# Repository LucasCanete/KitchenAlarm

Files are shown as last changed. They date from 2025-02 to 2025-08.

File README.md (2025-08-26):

# KitchenAlarm
A small Atmega168 based Kitchentimer to measure cooking time for your meals. Forget about downloading another app or using your phone. Do it the old fashioned way, like  it's the 90's. Put the pizza in the oven, configure your Kitchenalarm and let it beep like a fire alarm on steroids when your pizza is ready.

## Table of Contents
1. [About the Project](#about-the-project)
2. [Features](#features)
3. [Components](#components)
4. [Getting Started](#getting-started)
5. [Project Status](#project-status)

## About the project
This one was one of my first projects writing bare metal C. What i wanted to do is develop the simplest device possible, write the software, make a pcb and print a 3D case for it. A Timer is a device everyone is familiar with, so i decided to go for that. I took an atmega168, programmed it using avrdude and made a simple pcb for the circuitry using KiCad. Using the OnShape software i designed a case for the pcb and this was the end result.

## Features
- Rotary Encoder for configuring minutes and seconds
- 4 Digit 7 Segment Display for displaying the time
- Buzzer Alarm for beeping when time has runned up
- Deep sleep Mode after 1 Minute of not receiving instructions
- USB-C charger port with leds for indicating charging status

## Components
| Component | Model  | Manufacturer  |
|:---|:---:|---:|
| Microcontroller  | atmega168 | Microchip |
| 7 Seg. Display  | Generic | - |
| Rotary Encoder Module  | KY-040 | - |
| Battery Charger  | BQ24090 | Texas Instruments |

## Getting Started
### Install AVRDUDE
```
sudo apt install avrdude
```
### Download this repo
```
git clone https://github.com/LucasCanete/KitchenAlarm.git
```
### Build and upload 
Connect the KitchenAlarm to the PC using usbasp and upload the code:
```
cd KitchenAlarm/Software
$KitchenAlarm/Software make
$KitchenAlarm/Software make flash
```
### Use
The Kitchenalarm has a **Rotary Encoder** that lets you configure the Minutes and Seconds through the encoder's rotation.
1. Press the Rotary Encoder on the board to configure the Minutes and adjust it rotating the encoder 
2. Press it once again to configure the Seconds and rotate it to adjust 
3. Press the encoder one last time to activate the Timer with the Minutes and Seconds you configured in step 1 and step 2. The Timer will start counting down on the 7-Segment Display (To reset the countdown press the Encoder)
4. When the Timer reaches 00:00 (on the Display) the buzzer on the Board will start beeping. Your pizza is ready. Press the Encoder once to stop the beeping
5. The Kitchenalarm goes automatically to deep sleep if it is not given instructions. To wake it up just press the Encoder

<p align="center">
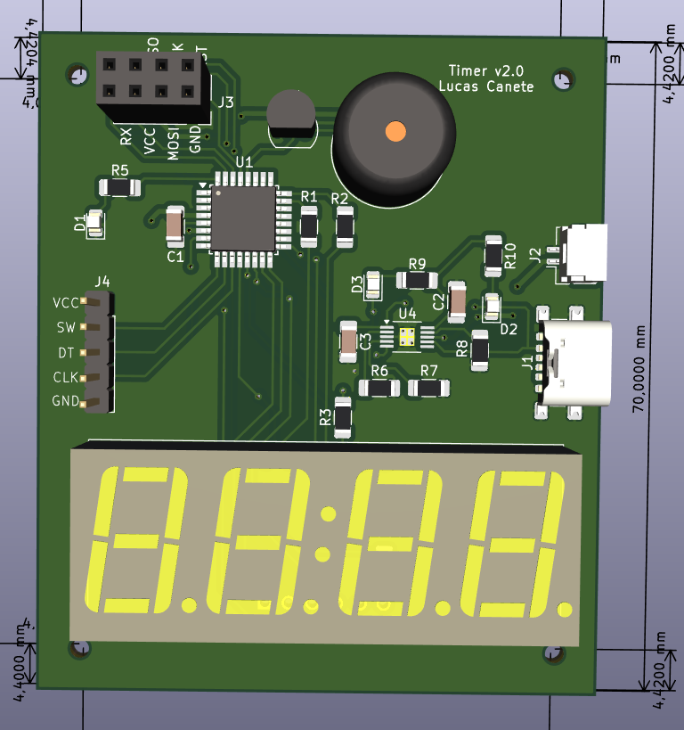
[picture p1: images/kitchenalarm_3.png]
Design
    
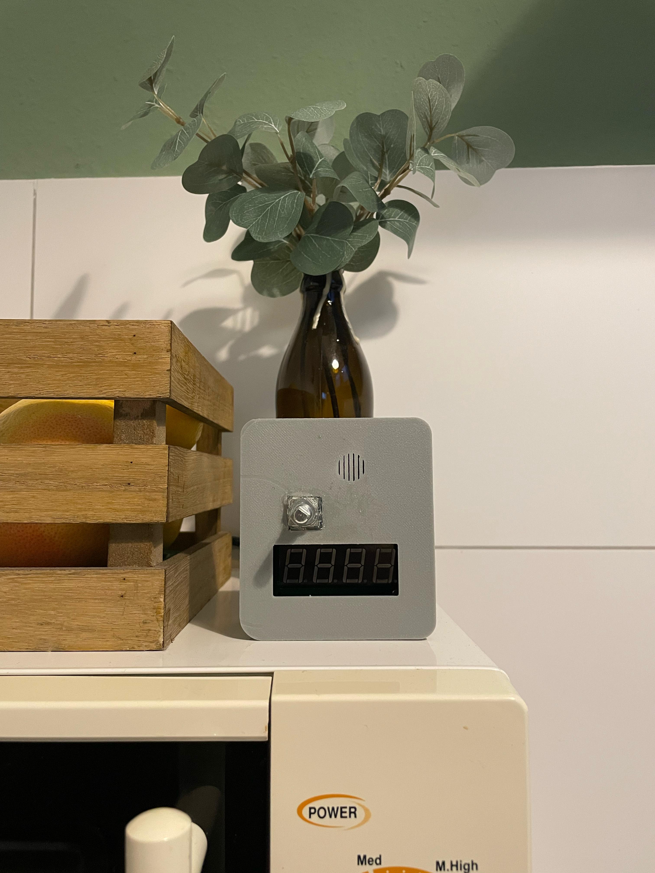
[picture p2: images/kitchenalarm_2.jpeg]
kitchenalarm
   
</p>

## Project Corretions
The project is still under development. Here are some improvement points for the next version. Crossed points havve alredy been implemented in the kicad design.
- [x] Add Rd resistors to USB-C for it to be detected as a passive device
- [x] Add resistor to buzzer transistor
- [ ] Use driver for efficient control of 7 segment display (MAX7219 or TM1637)

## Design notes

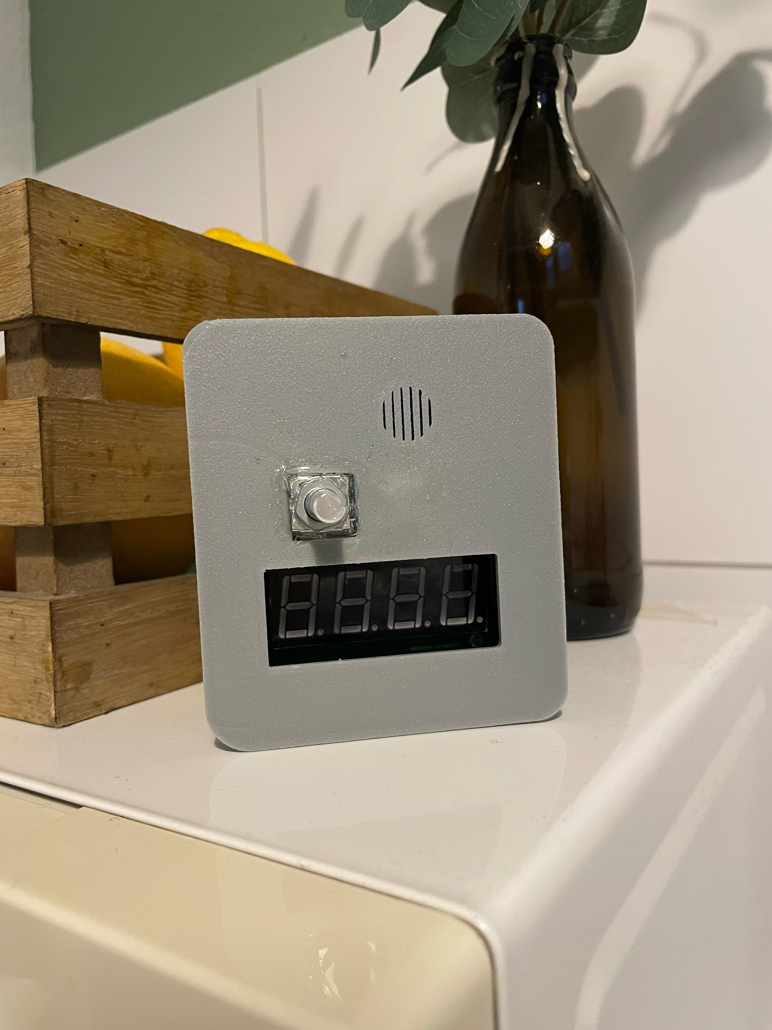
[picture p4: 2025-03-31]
images/kitchenalarm_1.jpeg

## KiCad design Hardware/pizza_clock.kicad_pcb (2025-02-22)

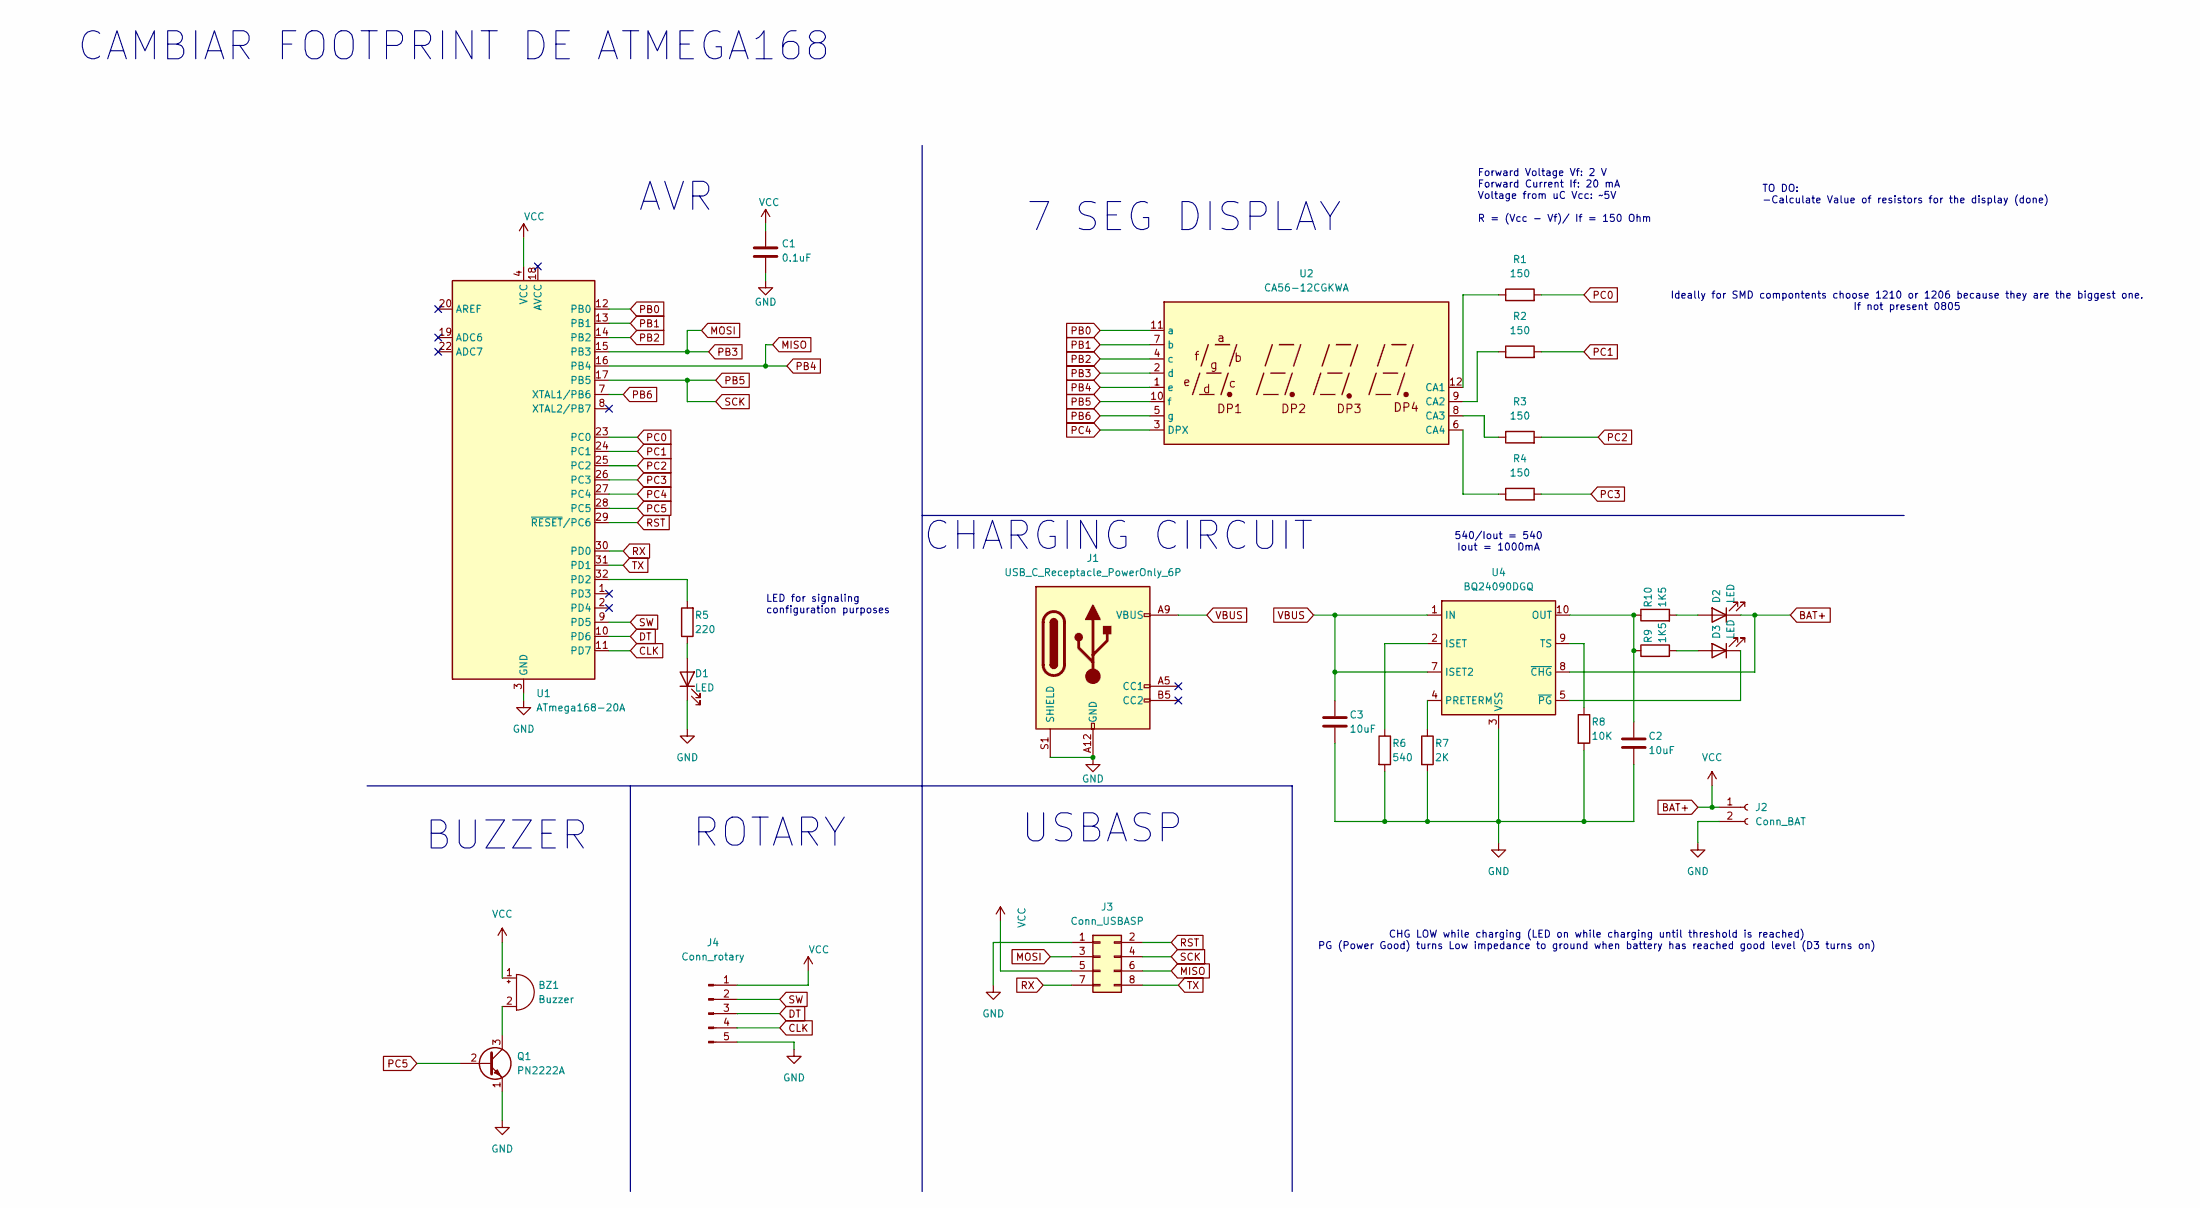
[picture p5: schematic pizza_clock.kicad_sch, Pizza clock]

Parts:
BZ1: Buzzer; Buzzer_12x9.5RM7.6
C1: 0.1uF; C_1206_3216Metric_Pad1.33x1.80mm_HandSolder
C2, C3: 10uF; C_1206_3216Metric_Pad1.33x1.80mm_HandSolder
D1, D2, D3: LED; LED_0805_2012Metric
J1: USB_C_Receptacle_PowerOnly_6P; USB_C_Receptacle_GCT_USB4135-GF-A_6P_TopMnt_Horizontal
J2: Conn_BAT; JST_GH_SM02B-GHS-TB_1x02-1MP_P1.25mm_Horizontal
J3: Conn_USBASP; PinSocket_2x04_P2.54mm_Vertical
J4: Conn_rotary; PinHeader_1x05_P2.54mm_Vertical
Q1: PN2222A; TO-92_Inline
R1, R2, R3, R4: 150; R_1206_3216Metric_Pad1.30x1.75mm_HandSolder
R5: 220; R_1206_3216Metric_Pad1.30x1.75mm_HandSolder
R6: 540; R_1206_3216Metric_Pad1.30x1.75mm_HandSolder
R7: 2K; R_1206_3216Metric_Pad1.30x1.75mm_HandSolder
R8: 10K; R_1206_3216Metric_Pad1.30x1.75mm_HandSolder
R9, R10: 1K5; R_1206_3216Metric_Pad1.30x1.75mm_HandSolder
U1: ATmega168-20A; TQFP-32_7x7mm_P0.8mm
U2: CA56-12CGKWA
U4: BQ24090DGQ; HVSSOP-10-1EP_3x3mm_P0.5mm_EP1.57x1.88mm_ThermalVias

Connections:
BAT+: BZ1.1 (-), C1.1, D2.1 (K), J2.1, J3.5, J4.1, U1.4 (VCC), U1.6 (VCC), U4.8 (~CHG)
CLK: J4.4, U1.11 (PD7)
DT: J4.3, U1.10 (PD6)
GND: C1.2, C2.2, C3.2, D1.1 (K), J1.A12 (GND), J1.B12 (GND), J1.S1 (SHIELD), J2.2, J3.1, J4.5, Q1.1 (E), R6.2, R7.2, R8.2, U1.3 (GND), U1.5 (GND), U1.21 (GND), U4.3 (VSS), U4.11 (VSS)
MISO: J3.6, U1.16 (PB4), U2.1 (e)
MOSI: J3.3, U1.15 (PB3), U2.2 (d)
unnamed: BZ1.2 (+), Q1.3 (C)
unnamed: D1.2 (A), R5.1
unnamed: D2.2 (A), R10.2
unnamed: D3.2 (A), R9.2
unnamed: D3.1 (K), U4.5 (~PG)
unnamed: R5.2, U1.32 (PD2)
unnamed: R1.1, U2.12 (CA1)
unnamed: R2.1, U2.9 (CA2)
unnamed: R3.1, U2.8 (CA3)
unnamed: R4.1, U2.6 (CA4)
unnamed: R6.1, U4.2 (ISET)
unnamed: C2.1, R9.1, R10.1, U4.10 (OUT)
unnamed: R7.1, U4.4 (PRETERM)
unnamed: R8.1, U4.9 (TS)
PB0: U1.12 (PB0), U2.11 (a)
PB1: U1.13 (PB1), U2.7 (b)
PB2: U1.14 (PB2), U2.4 (c)
PB5: J3.4, U1.17 (PB5), U2.10 (f)
PB6: U1.7 (XTAL1/PB6), U2.5 (g)
PC0: R1.2, U1.23 (PC0)
PC1: R2.2, U1.24 (PC1)
PC2: R3.2, U1.25 (PC2)
PC3: R4.2, U1.26 (PC3)
PC4: U1.27 (PC4), U2.3 (DPX)
PC5: Q1.2 (B), U1.28 (PC5)
RST: J3.2, U1.29 (~RESET/PC6)
RX: J3.7, U1.30 (PD0)
SW: J4.2, U1.9 (PD5)
TX: J3.8, U1.31 (PD1)
VBUS: C3.1, J1.A9 (VBUS), J1.B9 (VBUS), U4.1 (IN), U4.7 (ISET2)

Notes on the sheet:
7 SEG DISPLAY
Ideally for SMD compontents choose 1210 or 1206 because they are the biggest one. If not present 0805
CHG LOW while charging (LED on while charging until threshold is reached) PG (Power Good) turns Low impedance to ground when battery has reached good level (D3 turns on)
USBASP
CAMBIAR FOOTPRINT DE ATMEGA168
AVR
BUZZER
TO DO: -Calculate Value of resistors for the display (done)
540/Iout = 540 Iout = 1000mA
Forward Voltage Vf: 2 V Forward Current If: 20 mA Voltage from uC Vcc: ~5V R = (Vcc - Vf)/ If = 150 Ohm
CHARGING CIRCUIT
LED for signaling configuration purposes
ROTARY

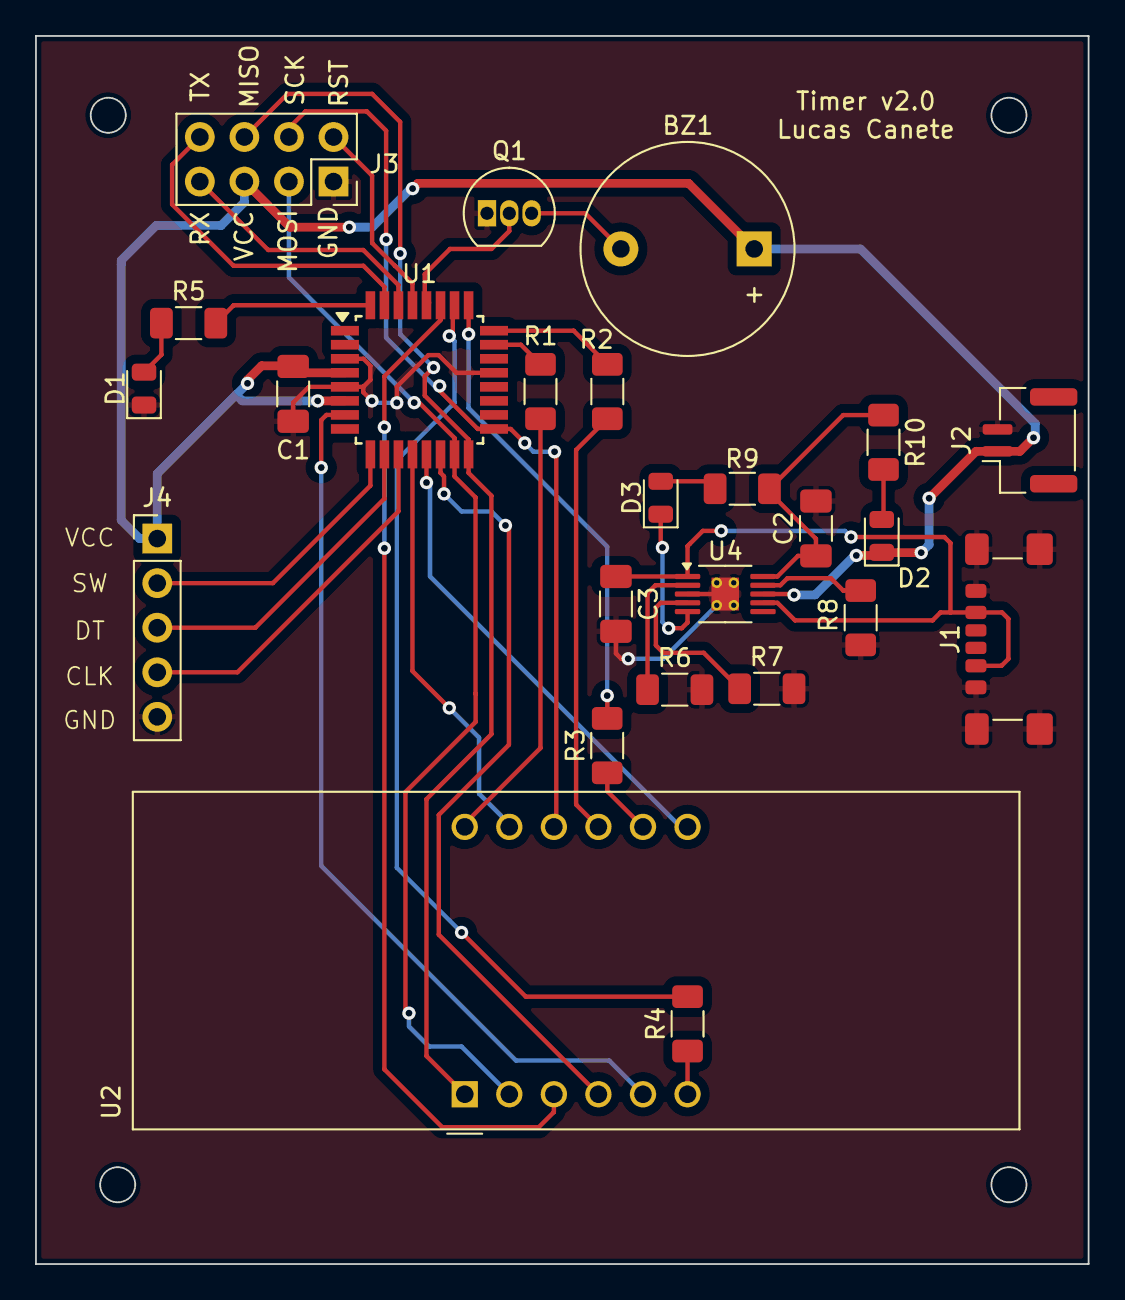
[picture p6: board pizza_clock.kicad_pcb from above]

Board: 2 copper layers, 60.0 x 70.0 mm, 25 parts (0 on the bottom side), 36 nets.

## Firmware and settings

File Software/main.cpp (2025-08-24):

#define F_CPU 1000000UL

#include <avr/io.h>
#include <util/delay.h>
#include <avr/interrupt.h>
#include <avr/sleep.h>
#include <avr/wdt.h>
#include "SevenSegmentDisplay.h"
#include "RotaryEncoder.h"
#include "defines.h"


int8_t unit_sec = 0;
int8_t ten_sec = 0;

int8_t unit_min = 0;
int8_t ten_min = 0;

volatile uint16_t COUNTER_TIMEOUT = 0;

namespace ButtonState {
  enum State {
    PRESSED = 0,
    NOT_PRESSED = 1
  };
}
ButtonState::State buttonStatus = ButtonState::NOT_PRESSED;

namespace Alarm {
  enum State {
    SET = 1,
    NOT_SET = 0
  };
}
Alarm::State alarmState = Alarm::NOT_SET;

typedef enum {IDLE, PROG_MIN, PROG_SEC, COUNTDOWN, BEEP} state_t;
state_t current_state = IDLE;
state_t prev_state = BEEP;

SevenSegmentDisplay display(A_PIN, &A_PORT, B_PIN, &B_PORT,
                            C_PIN, &C_PORT, D_PIN, &D_PORT,
                            E_PIN, &E_PORT, F_PIN, &F_PORT,
                            G_PIN, &G_PORT, DPX_PIN, &DPX_PORT,
                            CA1_PIN, &CA1_PORT, CA2_PIN, &CA2_PORT,
                            CA3_PIN, &CA3_PORT, CA4_PIN, &CA4_PORT);

RotaryEncoder rotary(&BUTTON_DIR, BUTTON_PIN, &DT_DIR, DT_PIN, &CLK_DIR, CLK_PIN);



volatile uint8_t prevButtonVal = 1; //default state HIGH because of PULLUP RESISTOR
ISR(PCINT0_vect){
    uint8_t currentButtonVal = rotary.readButton();
    //Button was pressed
    if(!currentButtonVal && prevButtonVal){
      // Detect falling edge → button was just pressed
      buttonStatus = ButtonState::PRESSED;
    }

    prevButtonVal = currentButtonVal;
}


ISR(TIMER1_COMPA_vect) {
  COUNTER_TIMEOUT++;

  //reduce countdown by one if alarm is set
  if(alarmState == Alarm::SET && (unit_min + ten_min + unit_sec+ten_sec > 0)){ unit_sec--;}

  else if (alarmState == Alarm::NOT_SET && current_state == IDLE && COUNTER_TIMEOUT == 60 ){
      COUNTER_TIMEOUT = 0;
      display.clear();

      set_sleep_mode(SLEEP_MODE_PWR_DOWN);   // Set power-down sleep mode
			cli(); //cli before sleep enable to avoid interferance with interrupts
			sleep_enable();   // Enable sleep mode
			sei();
			sleep_cpu();

  }
}

/**
 * @brief
 *
 * @param minute_unit
 * the unit part of the minute
 * @param minute_ten
 * the tenth part of the minute
 */

void UpdateMinutesUnit(int8_t *minute_unit, int8_t *minute_ten){

	if(*minute_unit > 9 && *minute_ten != 5) {
		(*minute_ten)++;
		*minute_unit = 0;
	}
	else if (*minute_unit < 0){
		(*minute_ten)--;
		*minute_unit = 9;

	}
	if(*minute_ten == 5 && *minute_unit > 9){
		*minute_ten = 0;
		*minute_unit = 0;
	}
	else if (*minute_ten < 0){
		*minute_ten = 5;
		*minute_unit = 9;
	}

};


/**
 * @brief
 *
 * @param sec_unit
 * the ones
 * @param sec_ten
 * the tens
 * @param min_unit
 * to bind it to the minutes variable
 */
void UpdateSecondsUnit(int8_t *sec_unit, int8_t *sec_ten, int8_t *min_unit ){


	 if(*sec_unit > 9 && *sec_ten != 5) {
		(*sec_ten)++;
		*sec_unit = 0;
	}
	else if (*sec_unit < 0){
		(*sec_ten)--;
		*sec_unit = 9;

	}

	if(*sec_ten == 5 && *sec_unit > 9){
			(*min_unit)++;
			*sec_ten = 0;
			*sec_unit = 0;
	}

	 else if (*sec_ten < 0){
			(*min_unit)--;
			*sec_ten = 5;
			*sec_unit = 9;
	}


};

void display_minutes(){
  display.first_digit(ON);
  display.show_value(ten_min);
  _delay_ms(1);
  display.clear();
  display.first_digit(OFF);

  display.decimal_point(ON);
  display.second_digit(ON);
  display.show_value(unit_min);
  _delay_ms(1);
  display.clear();
  display.second_digit(OFF);
  display.decimal_point(OFF);
}


void display_seconds(){

  display.third_digit(ON);
  display.show_value(ten_sec);
  _delay_ms(1);
  display.clear();
  display.third_digit(OFF);


  display.fourth_digit(ON);
  display.show_value(unit_sec);
  _delay_ms(1);
  display.clear();
  display.fourth_digit(OFF);
}


void initTimer_16bit(){

	TCCR1B |= (1<<WGM12); //set CTC mode CAPTURE COMPARE
	OCR1A = 976;
	TIMSK1 |= (1<<OCIE1A); //enable interrupt
	//timer every 1 second. For one minute it has to reache the ISR 60 times.
	sei(); //enable global interrupts
	TCCR1B |= (1<<CS12) | (1<<CS10); //set prescaler (CPU clock)/1024, CPUCLOCK by default = 1MHz

}

void initInterruptSW(){
  PCICR |= (1 << PCIE0); //activate interrupts from PCINT0 to PCINT7
  PCMSK0 |= (1 << PCINT2); //interrupt on PB2
}

 int main(){
   display.init();
   display.all_digits_off();

   rotary.init();

   initTimer_16bit();
   initInterruptSW();
   wdt_disable();

   BUZZER_DDR |= (1 << BUZZER_PIN);

   //disable Analog Comparator
   ACSR |= (1 << ACD);

   //turn off ADC
   ADCSRA &= ~(1 << ADEN);



   while(1){

     rotary_direction_t direction = rotary.getDirection();
     switch(current_state){
       case IDLE:

             if(current_state != prev_state){
               display.show_value(prev_state);
               _delay_ms(500);
               prev_state = current_state;
             }

            display_minutes();
            display_seconds();

            if(buttonStatus == ButtonState::PRESSED){
              buttonStatus = ButtonState::NOT_PRESSED;
              //prev_state = IDLE;
              current_state = PROG_MIN;
            }

            break;

       case PROG_MIN:

           if(current_state != prev_state){
    					_delay_ms(500);
    					prev_state = current_state;
    				}

            display_minutes();
            if(direction == CLOCKWISE){
              unit_min++;
              UpdateMinutesUnit(&unit_min, &ten_min);
            }
            else if (direction == COUNTERCLOCKWISE){
              unit_min--;
              UpdateMinutesUnit(&unit_min, &ten_min);
            }

            else if(buttonStatus == ButtonState::PRESSED){
              buttonStatus = ButtonState::NOT_PRESSED;
              prev_state = PROG_MIN;
              current_state = PROG_SEC;
            }

            break;

       case PROG_SEC:
             if(current_state != prev_state){
                _delay_ms(500);
                prev_state = current_state;
              }

              display_seconds();

             if(direction == CLOCKWISE){
               unit_sec++;
               UpdateMinutesUnit(&unit_sec, &ten_sec);
             }
             else if (direction == COUNTERCLOCKWISE){
               unit_sec--;
               UpdateMinutesUnit(&unit_sec, &ten_sec);
             }

             else if(buttonStatus == ButtonState::PRESSED){
               buttonStatus = ButtonState::NOT_PRESSED;
               prev_state = PROG_SEC;
               current_state = COUNTDOWN;
               alarmState = Alarm::SET; //start the alarm once for the next state
             }

             break;

       case COUNTDOWN:
            if(current_state != prev_state){
      				_delay_ms(500);
      				prev_state = current_state;
      			}
            display_minutes();
            display_seconds();


            UpdateSecondsUnit(&unit_sec, &ten_sec, &unit_min);
            UpdateMinutesUnit(&unit_min, &ten_min);

            if(buttonStatus == ButtonState::PRESSED){
              buttonStatus = ButtonState::NOT_PRESSED;
              prev_state = COUNTDOWN;
              current_state = IDLE;
              alarmState = Alarm::NOT_SET;

              unit_sec = 0;
              ten_sec = 0;

              unit_min = 0;
              ten_min = 0;
            }
            else if ((ten_min + unit_min + ten_sec + unit_sec) == 0){
              prev_state = COUNTDOWN;
              current_state = BEEP;
              alarmState = Alarm::NOT_SET;
            }
            break;

       case BEEP:
          BUZZER_PORT |= (1 << BUZZER_PIN);
          _delay_ms(300);
          BUZZER_PORT &= ~(1 << BUZZER_PIN);
          _delay_ms(500);

          if(buttonStatus == ButtonState::PRESSED){
            buttonStatus = ButtonState::NOT_PRESSED;
            prev_state = BEEP;
            current_state = IDLE;
          }

          break;
     }
   }
}

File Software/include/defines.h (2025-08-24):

#ifndef DEFINES_H
#define DEFINES_H

/* 4 DIGIT 7 SEGMENT DISPLAY*/

#define A_PIN     PD5
#define A_PORT    DDRD

#define B_PIN     PB1
#define B_PORT    DDRB

#define C_PIN     PC3
#define C_PORT    DDRC

#define D_PIN     PC5
#define D_PORT    DDRC

#define E_PIN     PD2
#define E_PORT    DDRD

#define F_PIN     PD6
#define F_PORT    DDRD

#define G_PIN     PC2
#define G_PORT    DDRC

#define DPX_PIN   PC4
#define DPX_PORT  DDRC

#define CA1_PIN     PB7
#define CA1_PORT    DDRB

#define CA2_PIN     PD7
#define CA2_PORT    DDRD

#define CA3_PIN     PB0
#define CA3_PORT    DDRB

#define CA4_PIN     PC1
#define CA4_PORT    DDRC

/* BUZZER */

#define BUZZER_PORT PORTC
#define BUZZER_DDR  DDRC
#define BUZZER_PIN  PC0


/* ROTARY ENCODER */

#define DT_DIR DDRD
#define DT_PIN PD4

#define CLK_DIR DDRD
#define CLK_PIN PD3

#define BUTTON_DIR DDRB
#define BUTTON_PIN PB2

#endif

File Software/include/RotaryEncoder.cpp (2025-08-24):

#include "RotaryEncoder.h"


#if 1
RotaryEncoder::RotaryEncoder(volatile uint8_t *buttonDDR, uint8_t buttonPin, volatile uint8_t *DTDDR, uint8_t DTPin, volatile uint8_t *CLKDDR, uint8_t CLKPin):
buttonDDR_(buttonDDR), buttonPin_(buttonPin), DTDDR_(DTDDR), DTPin_(DTPin), CLKDDR_(CLKDDR), CLKPin_(CLKPin){

}


void RotaryEncoder::init(){

  //button, dt and clk as inputs
  *buttonDDR_ &= ~(1 << buttonPin_);
  *DTDDR_ &= ~(1 << DTPin_);
  *CLKDDR_ &= ~(1<< CLKPin_);

  //assign ports from data direction register
  buttonPort_ = buttonDDR_ - 1;
  CLKPort_ = CLKDDR_ - 1;
  DTPort_ = DTDDR_ - 1;

}

//Rising EDGE
rotary_direction_t RotaryEncoder::getDirection() {
  currentclkstate = *CLKPort_ & (1 << CLKPin_);

  rotary_direction_t direction = NONE;

  if (currentclkstate != lastclkstate &&currentclkstate==0){
    uint8_t DT_State = *DTPort_ & (1 << DTPin_);

    if (DT_State != currentclkstate) direction = COUNTERCLOCKWISE; //CLOCKWISE;

    else if (DT_State == currentclkstate) direction = CLOCKWISE; //COUNTERCLOCKWISE;
  }
  lastclkstate = currentclkstate;
  return direction;
}


uint8_t RotaryEncoder::readButton() const {
  return *buttonPort_ & (1 << buttonPin_);

}

#endif

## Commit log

2024-10-28 Update main.c
    Disabled analog comparator and turned off ADC
2025-02-22 Uploaded KiCad files
    [pizza_clock.kicad_pcb, pizza_clock.kicad_sch]
2025-02-22 Added files to Hardware Directory
    [pizza_clock.kicad_pcb, pizza_clock.kicad_sch]
